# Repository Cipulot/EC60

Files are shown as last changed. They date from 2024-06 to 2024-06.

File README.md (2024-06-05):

# EC60

Open source universal 60% Electrostatic Capacitive PCB.

## **DEPRECATED**

EC60 is deprecated in favor of the new and improved version: EC 60X.

Please note that no further support will be provided, let alone give support for boards not sourced from my official runs or approved sources.

# EC 60X Will Be Available for direct purchase!

If you want to buy directly and support my work you can now do it so soon.

## Introduction

This project is a continuation of my development of open source EC boards.

The supported layout options are the following:

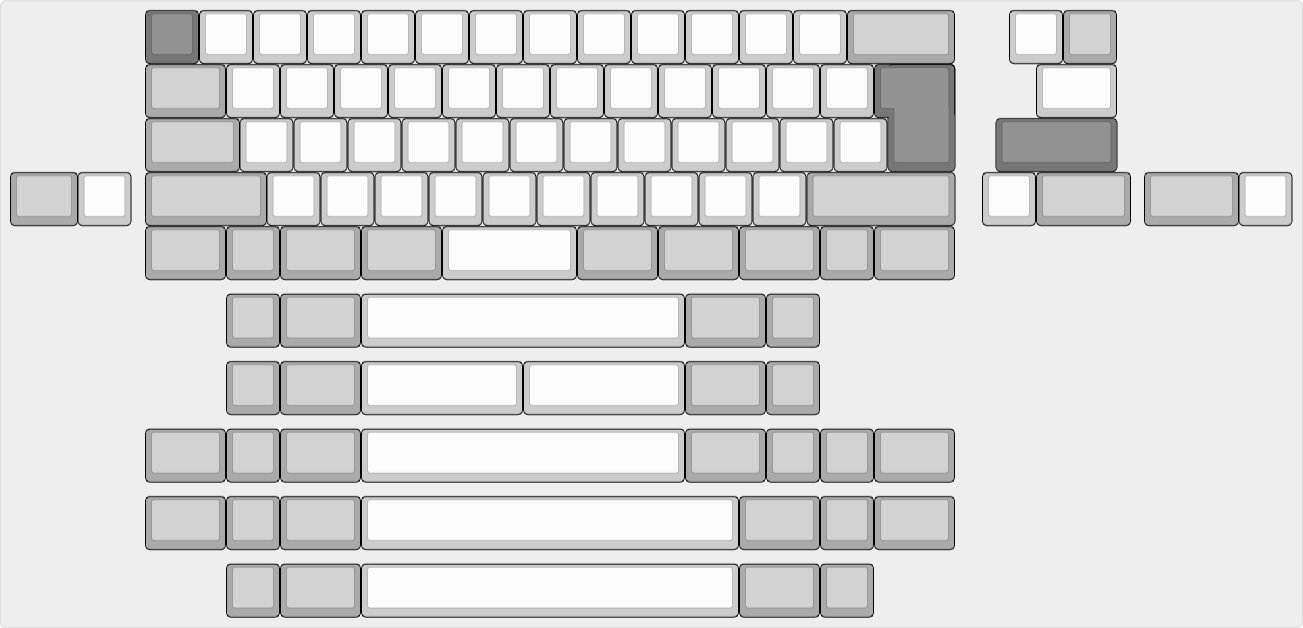
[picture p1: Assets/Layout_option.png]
Layout option


Mapping is purely for demonstration purposes, remapping of all keys is supported.

## Technical information

- Layout size: 60% (GH60 outline and mounting points, see pictures below)
- Compatible switches: EC switches (Topre and NIZ)
- Microcontroller: STM32F401
- Connector:
  - USB-C
  - JST connector for daughterboard
- Firmware compatibility: QMK (with VIA/VIAL support)
- Protection hardware (on all connection methods):
  - Fused
  - ESD protection

## Renders and Prototypes

### Render

Mainboard:

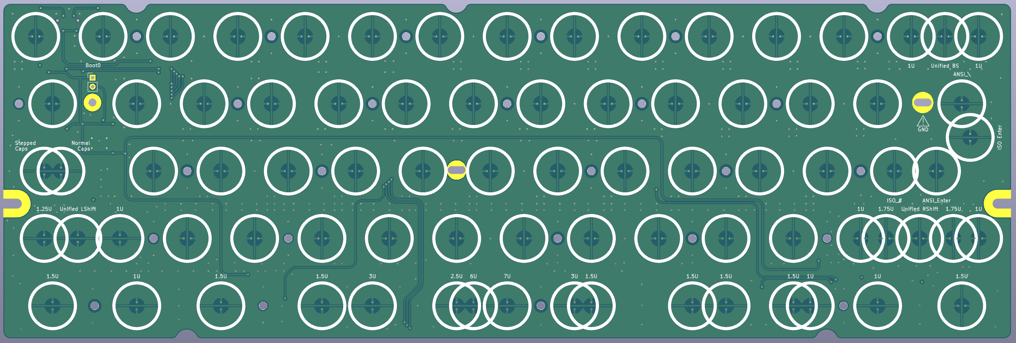
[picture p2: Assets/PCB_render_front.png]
PCB Front Render


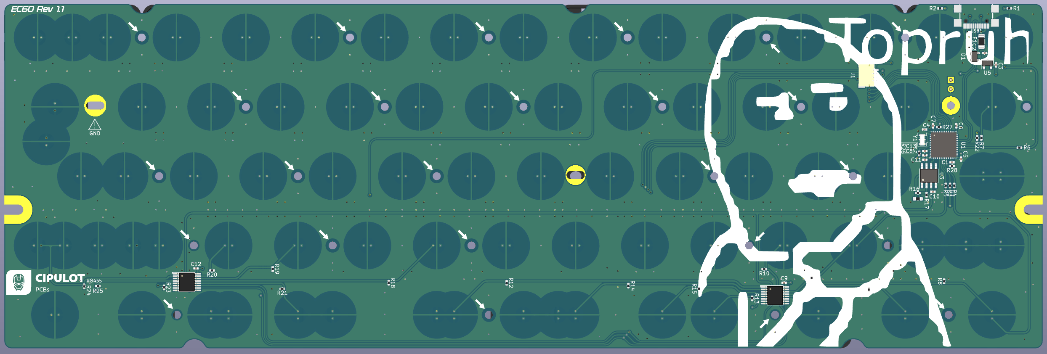
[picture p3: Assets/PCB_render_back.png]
PCB Back Render


### Prototype

#### Rev 1

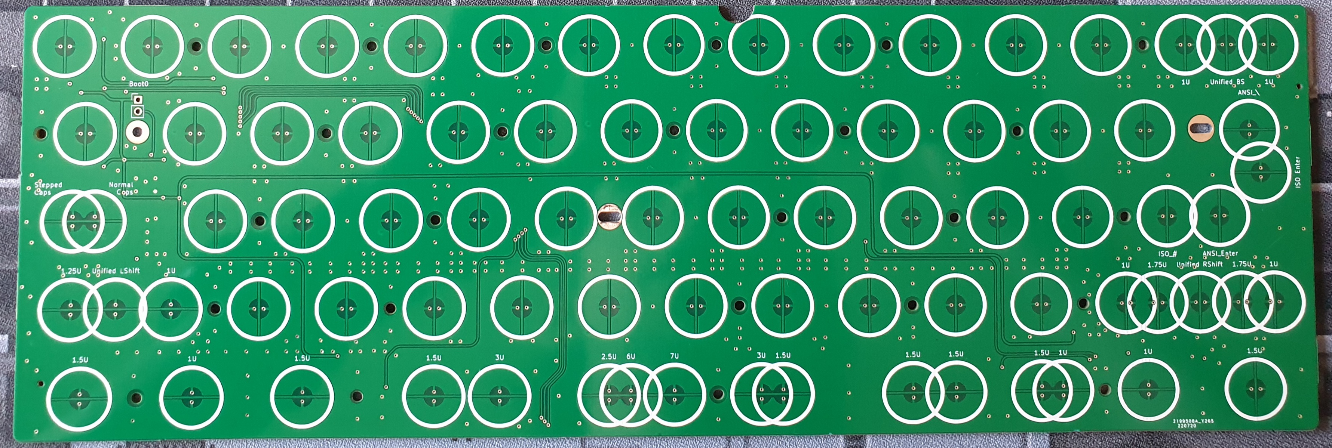
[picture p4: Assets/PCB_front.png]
PCB Front


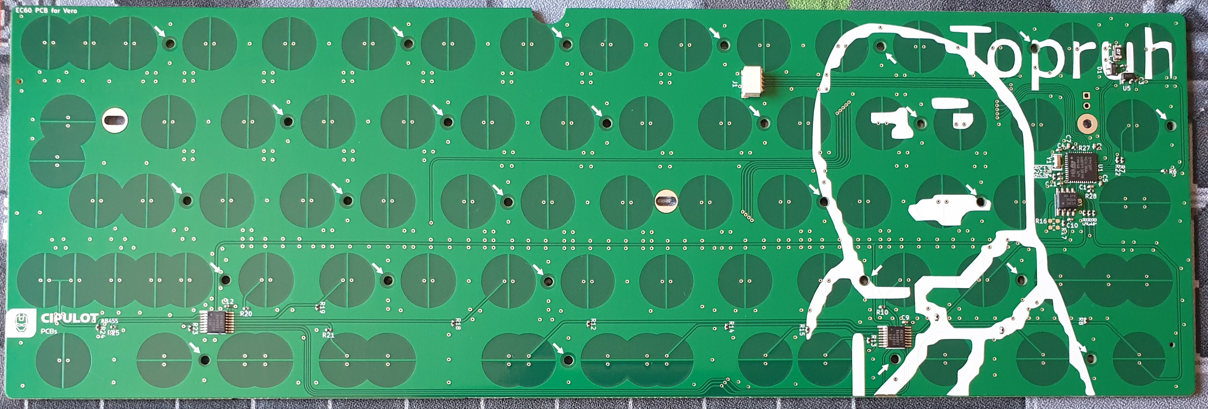
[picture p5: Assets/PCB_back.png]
PCB Back


#### Rev 1.1

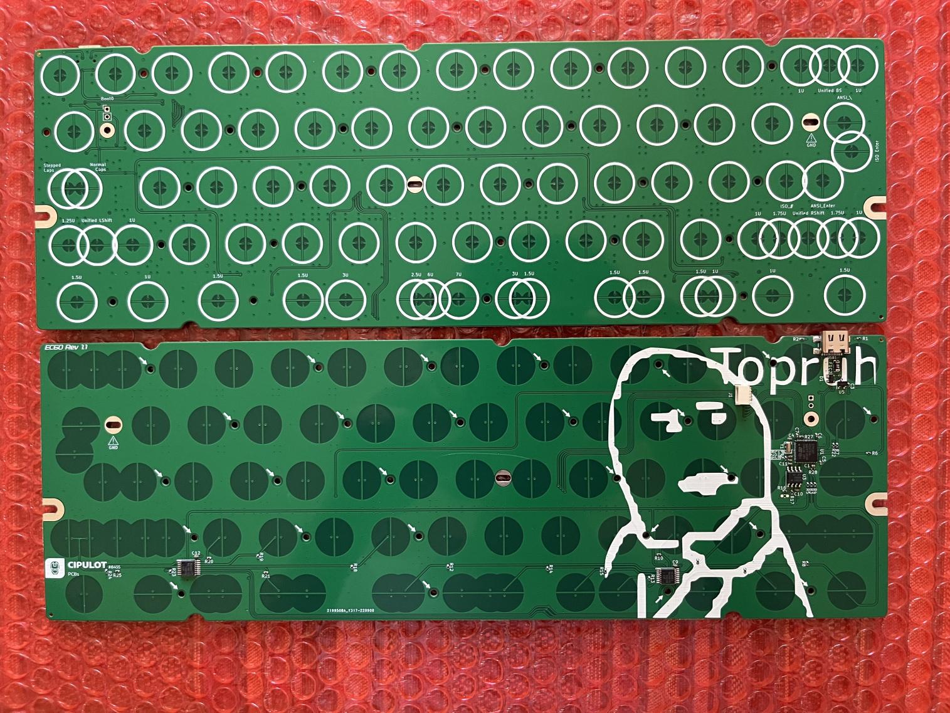
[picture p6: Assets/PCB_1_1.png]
PCB 1.1


_NOTE_: the prototype PCB for Rev1 doesn't include a USB port and the JST connector is in a different position compared to the one in the render. This is because the above was a modified version of the PCB to be used in Vero. For all intents and purposes, the PCB is the same.

## Revisions and relative features

### Rev 1

This revision implements all the main features of the PCB.

### Rev 1.1

This revision implements some changes:

- Changed the USB-C port to a different part that is more readily available
- reassigning of some GPIO port functions to avoid problems during compilation and boot sequence.
- connection of one of the mounting holes to the GND plane.
- some minor changes in silkscreen

#### Connectivity

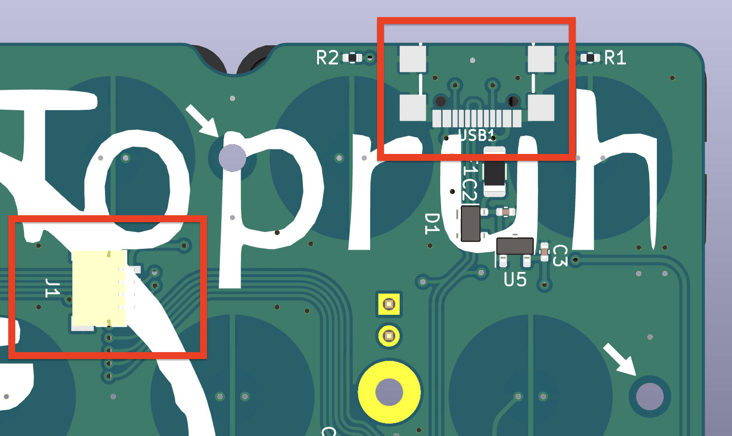
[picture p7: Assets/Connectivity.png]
Connectivity


Both onboard USB-C and JST connectors are supported. In both cases the protection features are preserved (fused and ESD).

## PCB order procedure

In order to have me highers compatibility possible with PCB manufacturers, I decided to design the board around the [JLC7628 Stackup](https://cart.jlcpcb.com/impedance#:~:text=4%2DLayer%20Impedance%20Control%20Stackup) from JLCPCB.

The rational behind this is that the JCPCB stackup is relatively cheap and if the board worked with the stackup, it would be easier to get the board to work with pretty much any other many that offer an equivalent stackup and higher prices.

### Production files

The production can be found in the [Production folder](/Production).

As usual the `*.zip` files are the gerber files, `BOM-*.csv` are the BOM (Bill Of Material) files and `POS-*.csv` are the POS/CPL (Footprint POSition/Component Placement List) files.

## Mainboard

As mentioned above, the mainboard is designed around the JLCPCB stackup. The mainboard is a 4 layer board.

Here are the options to select when ordering the mainboard:

- PCB thickness: 1.6mm or 1.2mm
- Impedance: NO
- Layer stackup:
  - L1(Top layer): `EC60-F_Cu.gbr`
  - L2(Inner layer1): `EC60-In1_Cu.gbr`
  - L3(Inner layer2): `EC60-In2_Cu.gbr`
  - L4(Bottom layer): `EC60-B_Cu.gbr`
- PCB Color: whatever you like
- Surface Finish: whatever you like
- Material Type: `FR-4 TG155`

All the other options can be left as default.

#### Assembly options

Here follows the options to be used for assembly:

- Assembly Side: Bottom
- Tooling holes: `Added by JLCPCB`
- Confirm Parts Placement: `yes`

**NOTES ABOUT THE OPTIONS**

- Once you upload the gerber files wait for the system to automatically recognize the board outline and layers. It will take a while, be patient.

- `PCB thickness` has been tested on both 1.6mm and 1.2mm so it's your call on which one to use.

- For `Material Type` I strongly suggest to use `FR-4 TG155`, using the standard `FR4-Standard TG130-140` material might result in the board delamination and generally is not advised on 4 layer boards.

## License

<br />This work is licensed under a <a rel="license" href="http://creativecommons.org/licenses/by-nc-sa/4.0/">Creative Commons Attribution-NonCommercial-ShareAlike 4.0 International License</a>.

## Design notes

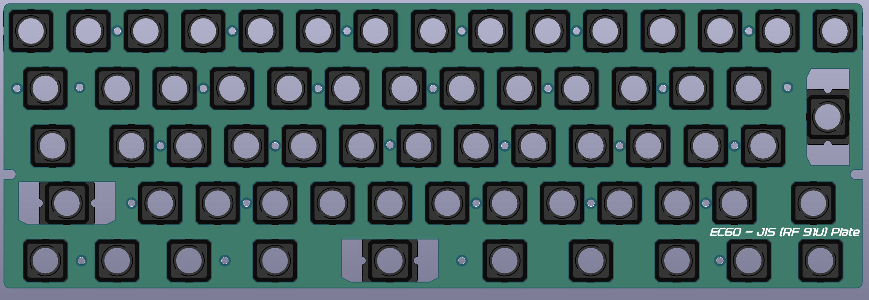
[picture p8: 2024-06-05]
Assets/Plate_render_jis.png

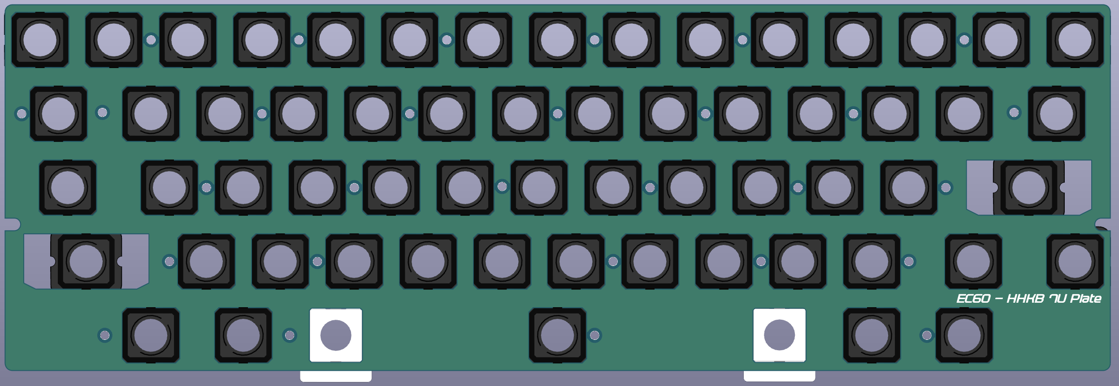
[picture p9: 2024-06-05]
Assets/Plate_render_hhkb_7u.png

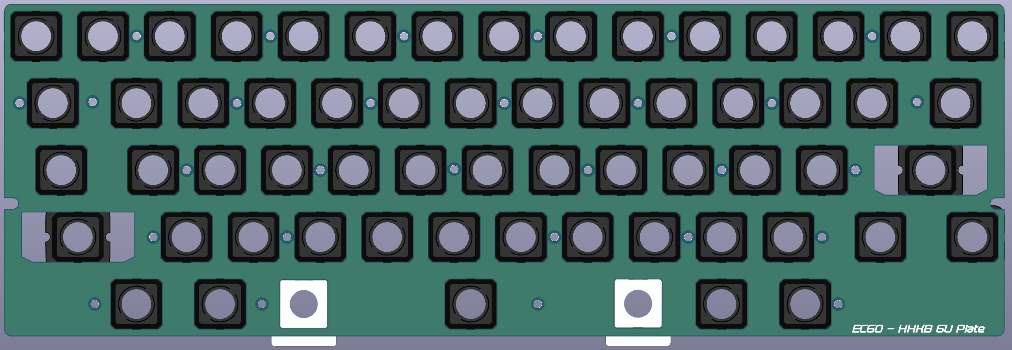
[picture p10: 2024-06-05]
Assets/Plate_render_hhkb_6u.png

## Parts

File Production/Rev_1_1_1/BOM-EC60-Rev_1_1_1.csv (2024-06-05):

Comment | Designator | Footprint | LCSC
1k | R17 | R_0402_1005Metric | C11702
STM32F401CBUx | U1 | QFN-48-1EP_7x7mm_P0.5mm_EP5.6x5.6mm | C118825
OPA350 | U3 | SOIC-8_3.9x4.9mm_P1.27mm | C13388
JST | J1 | JST-SR-4 | C145956
220p | C10 | C_0402_1005Metric | C1530
4.7u | C1 | C_0402_1005Metric | C23733
100 | R3,R4,R5,R6,R7 | R_0402_1005Metric | C25076
100k | R10,R11,R12,R13,R14,R15,R16,R18,R19,R20,R21,R22,R23,R24,R25,R8,R9 | R_0402_1005Metric | C25741
10k | R26,R27,R28 | R_0402_1005Metric | C25744
5.1k | R1,R2 | R_0402_1005Metric | C25905
PRTR5V0U2X | D1 | SOT-143 | C2827688
TYPEC-304YSSW-ACP16 | USB1 | TYPEC-304YSSW-ACP16 | C2840392
100n | C11,C12,C4,C5,C6,C7,C8,C9 | C_0402_1005Metric | C307331
1u | C13,C2,C3 | C_0402_1005Metric | C52923
XC6206PxxxMR | U5 | SOT-23 | C5446
74HC4051 | U2,U4 | TSSOP16 | C5645
500mA | F1 | Fuse_1206_3216Metric | C70076
8 MHz | Y1 | Resonator_SMD_Murata_CSTxExxV-3Pin_3.0x1.1mm | C907975

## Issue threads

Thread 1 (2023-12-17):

THE "MATRIX_COL_CHANNELS" question

weekinro, 2023-12-17:
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
Hello bro, may I ask how the numbers in the picture were obtained

Cipulot, 2023-12-17:
The numbers in the list correspond to the channel number of the AMUX going from Col0 --> Colx.

weekinro, 2023-12-18:
> @weekinro列表中的数字对应于从 Col0 --> Col0 开始的 AMUX 的通道号。科尔克斯。

thank you very much，

Closed 2023-12-17.

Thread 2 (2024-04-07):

4 layer vs 2 layer

regfod, 2024-04-07:
Not an issue, just curious, is it possible to build with only two layer PCB rather than 4 layer? I can see the routing are nicer. Are there specific reason for the inner 2 layers?

Cipulot, 2024-04-09:
Could be, but the use of 4 layer has advantages that go beyond the "easier" routing, such as better isolation and other benefits that were tested during various iterations.

Closed 2024-04-09.
